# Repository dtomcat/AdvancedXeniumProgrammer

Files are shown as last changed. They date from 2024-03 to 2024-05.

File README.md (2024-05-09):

# OpenXenium JTAG and Flash Memory Chip programmer

**This is based on work done by [kooscode](https://github.com/kooscode/xenium-programmer) and [Ryzee119](https://github.com/ryzee119/openxenium) with modifications to program the bare ICs.  Most of the code here was done by kooscode (please visit the link above).

--------------

## * Read: ["Home Brew" on ORIGINAL XBOX](XBOX.md) - a detailed article on why and how *

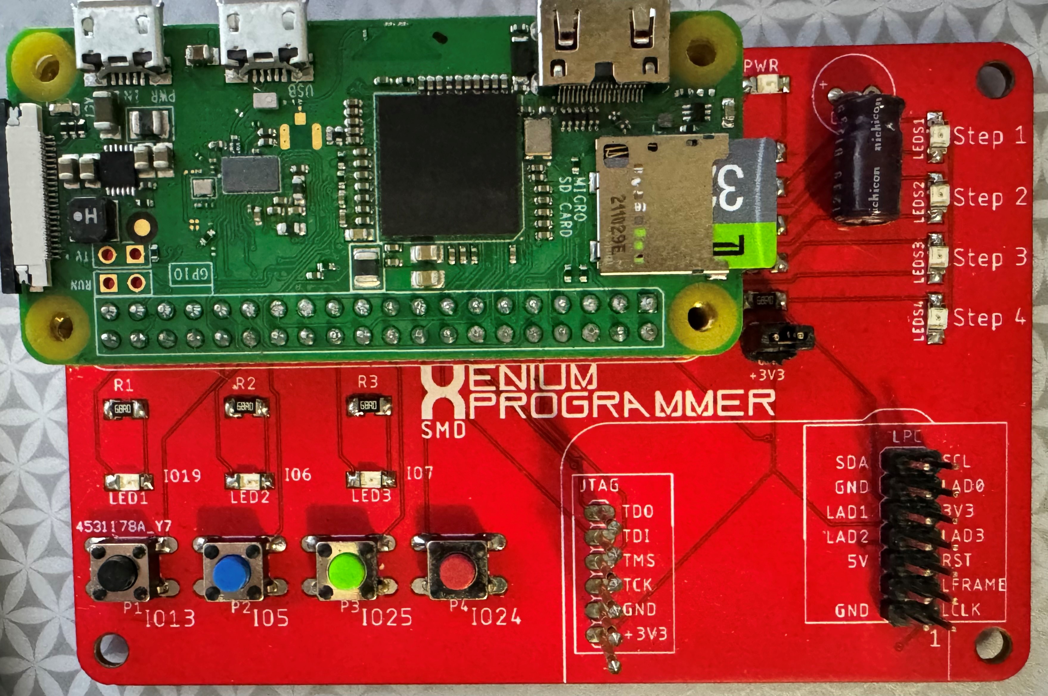
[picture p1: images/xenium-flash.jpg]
xenium-programmer


The tools in this repo will allow you to use a Raspberry PI to program the CPLD and Flash Memory chips of the OpenXenium via Jtag and a custom 4-bit bus NOR Flash programming protocol.
Original project mentioned above allowed the use of an Onion Omega2+... This has been removed for this project. 

### Raspberry PI:
- This has only been tested on PI Zero W and PI 3B+ models so far.

https://www.pishop.us/product/raspberry-pi-zero-w/

-------------
## INSTALLING THE XENIUM PROGRAMMER
**The scripts assumes user of "pi"...  if using a different user, you'll need to manually change "pi" to your username in the scripts**
- After the OS has been written to your SD card, insert SD card into PC.
    - Add the following to the last line in "config.txt":   `enable_uart=1`
        - This is required to allow the PWR LED to function properly.
- Save edit and eject SD Card.  Insert SD card into Pi and boot up.
- Connect to the PI via SSH or Serial terminal
- If git is not installed, you need to install it:
    - `sudo apt-get install git`
- Clone this repo by running: `git clone https://github.com/dtomcat/AdvancedXeniumProgrammer.git`
- Change to program directory: `cd AdvancedXeniumProgrammer`
- Fix permission on install file:  `chmod 755 install`
- Then run: `./install`
- Setup service to listen for button presses:
    - `sudo cp xenium.service /etc/systemd/system/xenium.service`
    - `sudo systemctl daemon-reload`
    - `sudo systemctl enable xenium`
    - `sudo service xenium start`

## UPDATING XENIUM PROGRAMMER

- Connect to the PI via SSH or Serial terminal 
- Pull the latest code with: `git pull`
- Then run: `./install` 

-------------
## STATUS LED MEANING (From top to bottom)

- First:  Programming CPLD with BIT BANG firmware
- Second: Programming Flash with specified OS
- Third:  Verifying flash was programmed successfully
- Forth:  Programing CPLD with OpenXenium firmware

-------------
## PROGRAMMING THE XENIUM CPLD AND/OR FLASH MEMORY (STANDALONE)

Note: You will need to provide your own PrometheOS bin file. (save it in the /xenium-bin folder as promOS.bin)

- After the PI has fully booted and the green led is on...
    - Press the FIRST button to program the OpenXenium with XeniumOS.
    - Hold the FIRST button to program the OpenXenium with PrometheOS.
    - Press the SECOND button to program the flash chip with XeniumOS. (**The CPLD must be programmed with the Bit Bang firmware or this will fail.)
    - Hold the SECOND button to program the flash chip with PrometheOS. (**The CPLD must be programmed with the Bit Bang firmware or this will fail.)
    - Press the THIRD button to program the CPLD with the OpenXenium Firmware.
    - Hold the THIRD button to program the CPLD with the BitBang Firmware.
    - Press the FOURTH button to clear any errors.
    - Hold the FOURTH button to shutdown the Raspberry Pi.

-------------
## PROGRAMMING THE XENIUM CPLD AND/OR FLASH MEMORY (SSH/SERIAL)
This is good to do if you keep getting an error trying to program the chips. (Red LED remains on)

Note: You will need to provide your own PrometheOS bin file. (save it in the /xenium-bin folder as promOS.bin)

- Connect to the PI via SSH or Serial terminal
- Change dir to AdvancedXeniumProgrammer
- You can program CPLD and FLASH in one single step with XeniumOS (XOS).
    - Run: `./xenium-programmer-smd`
- You can program CPLD and FLASH in one single step with PrometheOS (PromOS).
    - Run: `./PromOS-programmer-smd`
- You can program just the CPLD in one two ways.
    - To program the Bit Bang firmware: 
        - Run: `./BitBangOnly`
    - To program the OpenXenium firmware: 
        - Run: `./OX-Only_SMD`
- You can program just the Flash in oe of two ways. (The CPLD MUST have the Bit Bang Firmware loaded)
    - To program XOS:
          - Run: `./FlashOnly`
    - To program PromOS:
          - Run: `./FlashOnlyProm`

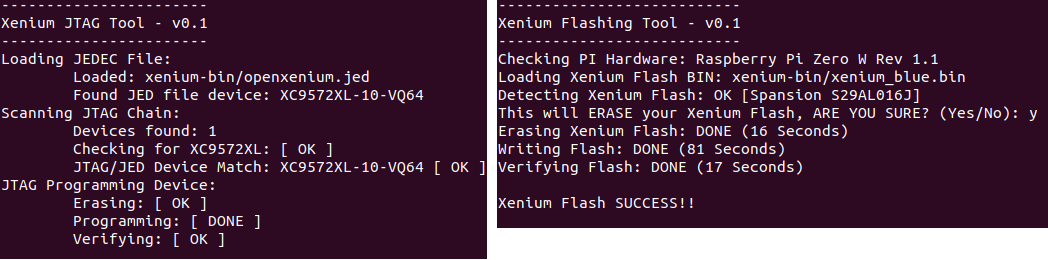
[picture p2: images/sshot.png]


-------------
### 3D PRINTED CASE

Just a quick and simple design I put together.  I'm sure this thing could be improved upon greatly.  Sharing for anyone wanting it.

NOTE:  for the "light pipes", I just used some clear PLA (2.90mm not standard 1.75) filament. 

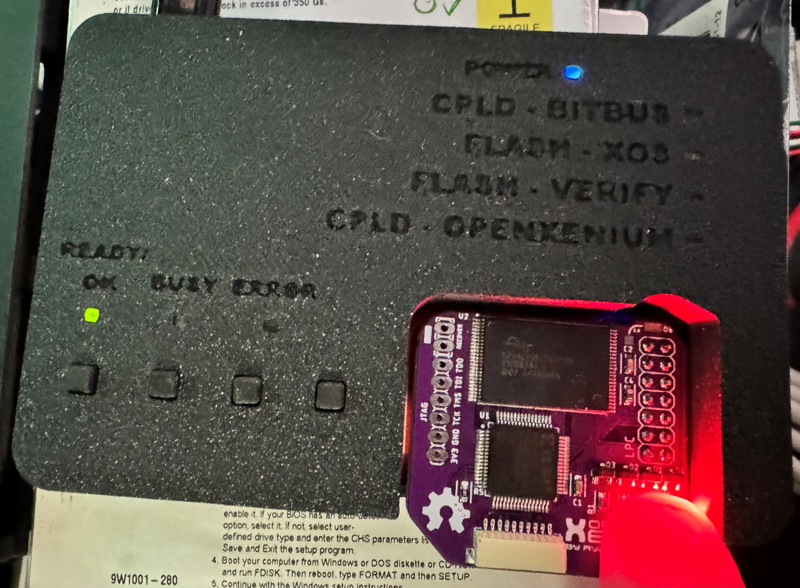
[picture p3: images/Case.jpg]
3D Case


--------------
### PC BOARD

Huge thanks to James Bolding for the Original Eagle PCB hardware design!
This PCB design is based on his original work.  

- You can use the FREE Eagle PCB to load this up or just use the gerber files to have the PCB made at OSH Park!

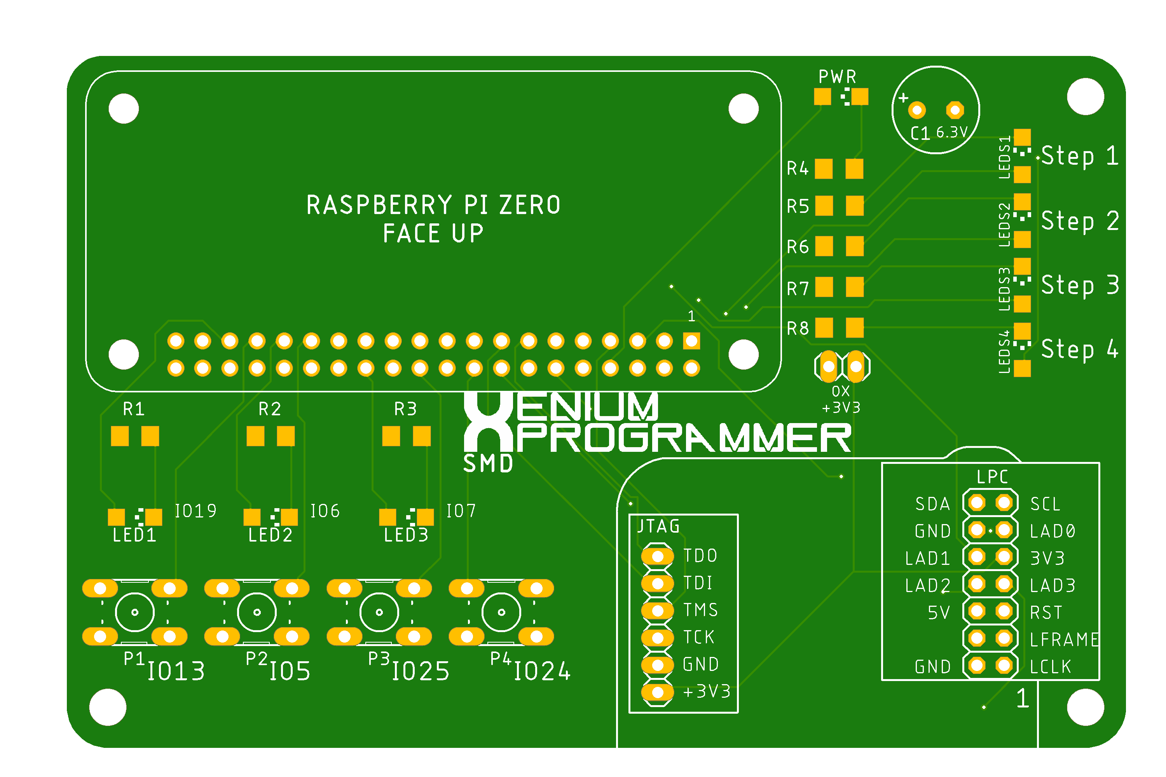
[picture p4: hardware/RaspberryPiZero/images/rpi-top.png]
RPI PCB


--------------

### PARTS NOT LISTED IN BOM
There are a couple parts not listed in BOM that could be helpful.
- Pin headers 2.54 spacing
    - 1 2x7 for LPC port
    - 1 1x2 for 3v3 (Optionally... but connect two points with solder)
        - Will need a 2-Pin Jumper/Bridge Cap if installing 1x2 pin header
- 6 Pogo pins (P75-E3 pogo pins seem to work the best)

-------------
## CREDITS

- Koos du Preez - Creator (kdupreez@hotmail.com - Comments, improvements, critique, etc. is welcome!)
- Dtomcat - SMD programmer PCB design and code split to allow status LEDs.
- James Bolding - Orignal hardware design and PCB!
- Ryzee119 -  OpenXenium Firmware and hardware and all round awesomeness!
- XC3SPROG - Not sure who to thank here, but the source code was pivotal in making this work!

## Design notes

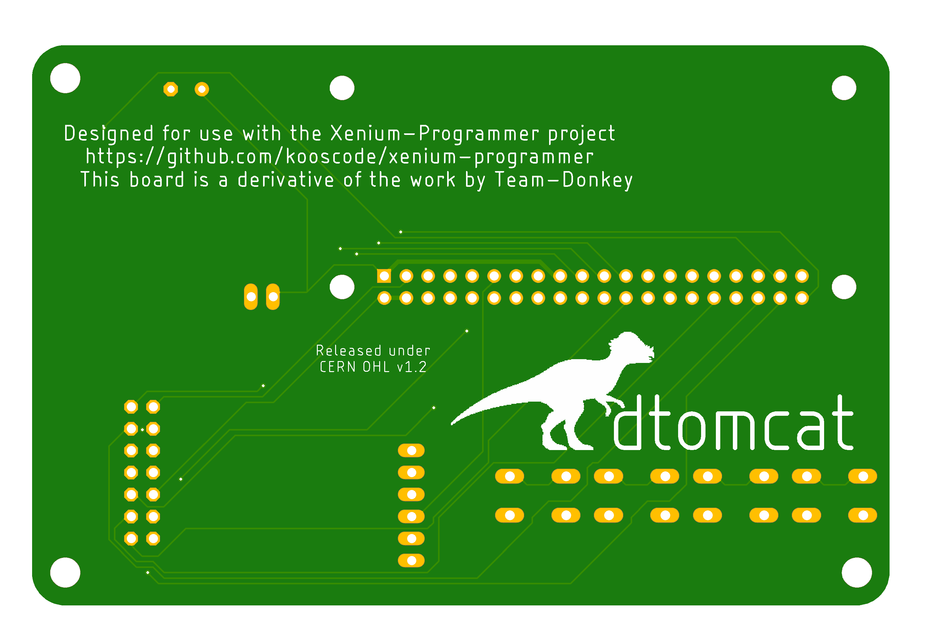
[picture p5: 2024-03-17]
hardware/RaspberryPiZero/images/rpi-bottom.png

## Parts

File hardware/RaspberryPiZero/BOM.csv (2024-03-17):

Reference | Qty | Description | Part Number | Manufacturer | Digikey
R1,R2,R3,R5,R6,R7,R8 | 7 | RES 68 OHM 1% 1/4W 1206 | RC1206FR-1068RL | YAGEO | 13-RC1206FR-1068RLCT-ND
R4 | 1 | RES 15 OHM 1% 1/4W 1206 | RC1206FR-1015RL | YAGEO | 13-RC1206FR-1015RLCT-ND
PWR | 1 | LED BLUE CLEAR 1206 SMD | LTST-C150TBKT | Lite-On Inc. | 160-1643-1-ND
LED1 | 1 | LED GREEN CLEAR 1206 SMD | LTST-C150KGKT | Lite-On Inc. | 160-1404-1-ND
LED2 | 1 | LED YELLOW CLEAR 1206 SMD | LTST-C150KSKT | Lite-On Inc. | 160-1406-1-ND
LED3 | 1 | LED RED CLEAR 1206 SMD | LTST-C150KRKT | Lite-On Inc. | 160-1405-1-ND
LEDS1,LEDS2,LEDS3,LEDS4 | 4 | LED ORANGE CLEAR 1206 SMD | LTST-C150KFKT | Lite-On Inc. | 160-1403-1-ND
C1 | 1 | CAP ALUM 150UF 20% 6.3V RADIAL | UPW0J151MED | Nichicon | 493-1698-ND
P1,P2,P3,P4 | 4 | SWITCH TACTILE SPST-NO 0.05A 24V | 1825910-6 | TE Connectivity ALCOSWITCH Switches | 450-1650-ND
RPI-CONN | 1 | CONN HDR 40POS 0.1 TIN PCB | PPTC202LFBN-RC | Sullins Connector Solutions | S6104-ND

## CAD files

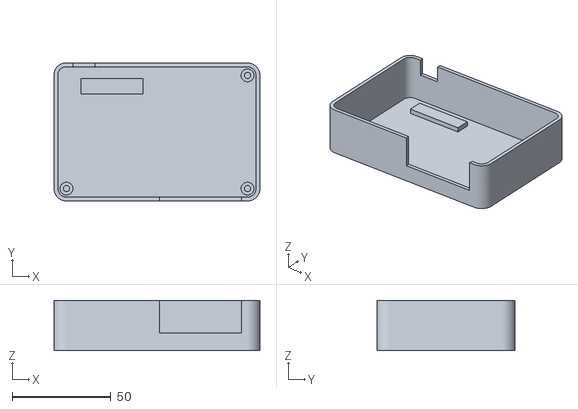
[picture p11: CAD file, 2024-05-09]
3D Case/ADV case Base.stl
104.1 x 69.8 x 25.5

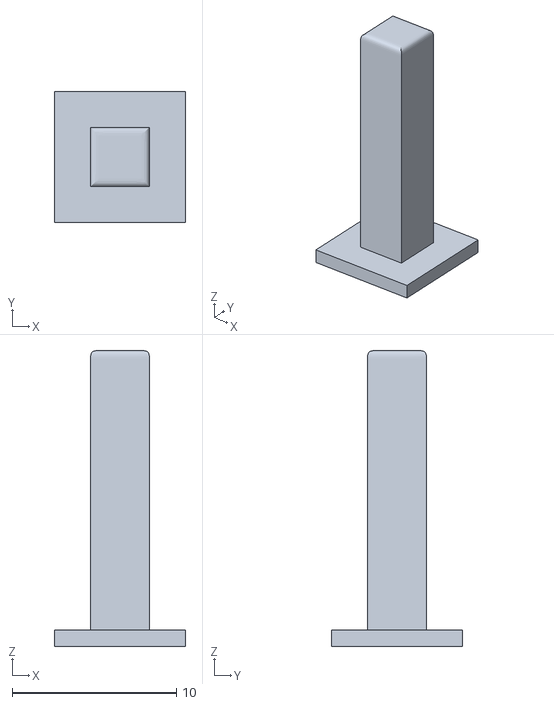
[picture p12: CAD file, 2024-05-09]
3D Case/ADV case Button.stl
7.99 x 7.99 x 18.0

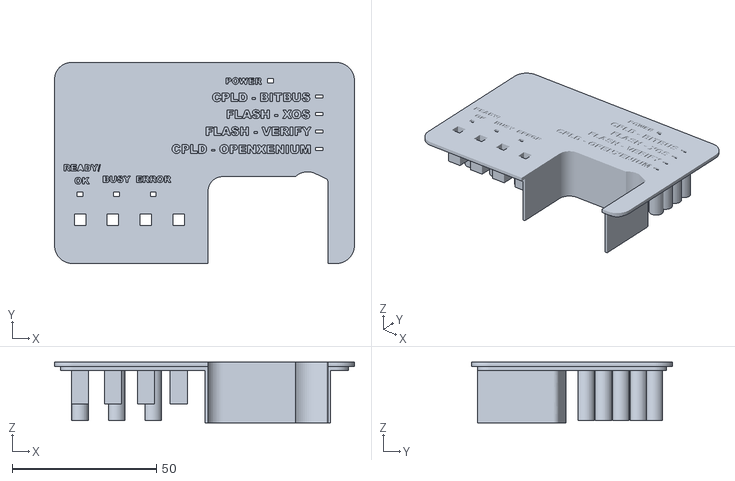
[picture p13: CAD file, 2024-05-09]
3D Case/ADV Case Lid.stl
104.1 x 69.8 x 21.1

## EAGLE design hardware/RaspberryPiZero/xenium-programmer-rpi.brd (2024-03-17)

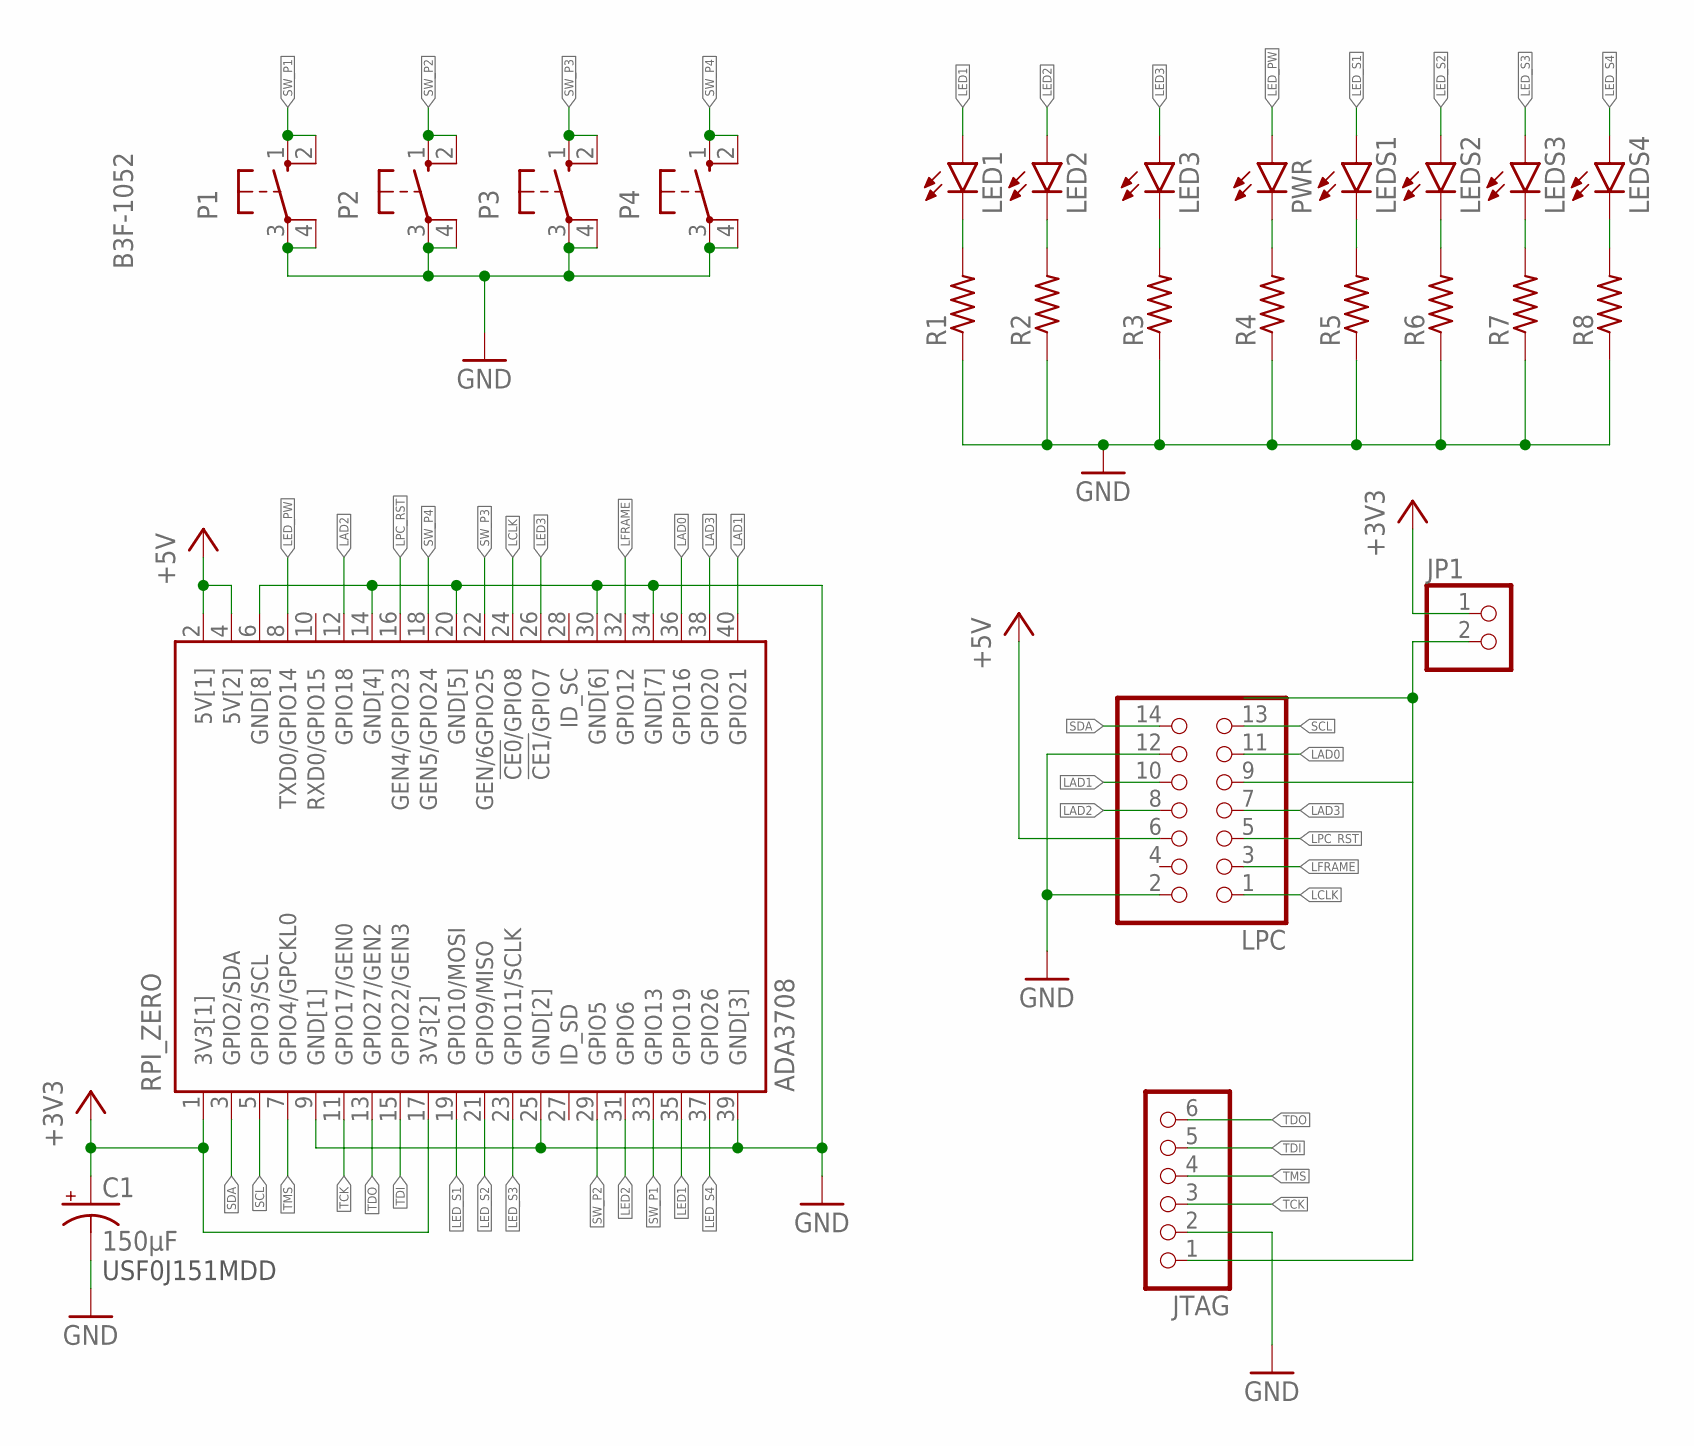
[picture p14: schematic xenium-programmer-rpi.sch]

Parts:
C1: 150µF; E3,5-8
JP1: PINHD-1X2; 1X02
JTAG: PINHD-1X6; 1X06
LED1, LED2, LED3: LEDCHIPLED_1206; CHIPLED_1206
LEDS1, LEDS2, LEDS3, LEDS4: LEDCHIPLED_1206; CHIPLED_1206
LPC: PINHD-2X7; 2X07
P1, P2, P3, P4: B3F-1052; B3F-10XX
PWR: LEDCHIPLED_1206; CHIPLED_1206
R1, R2, R3, R4, R5, R6, R7, R8: R-US_R1206; R1206
RPI_ZERO: ADA3708; ADA3708_RPI-ZERO

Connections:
+3V3: C1.+, JP1.1, RPI_ZERO.1 (3V3[1]), RPI_ZERO.17 (3V3[2])
+5V: LPC.6, RPI_ZERO.2 (5V[1]), RPI_ZERO.4 (5V[2])
GND: C1.-, JTAG.2, LPC.2, LPC.12, P1.3, P1.4 (P1), P2.3, P2.4 (P1), P3.3, P3.4 (P1), P4.3, P4.4 (P1), R1.1, R2.1, R3.1, R4.1, R5.1, R6.1, R7.1, R8.1, RPI_ZERO.6 (GND[8]), RPI_ZERO.9 (GND[1]), RPI_ZERO.14 (GND[4]), RPI_ZERO.20 (GND[5]), RPI_ZERO.25 (GND[2]), RPI_ZERO.30 (GND[6]), RPI_ZERO.34 (GND[7]), RPI_ZERO.39 (GND[3])
LAD0: LPC.11, RPI_ZERO.36 (GPIO16)
LAD1: LPC.10, RPI_ZERO.40 (GPIO21)
LAD2: LPC.8, RPI_ZERO.12 (GPIO18)
LAD3: LPC.7, RPI_ZERO.38 (GPIO20)
LCLK: LPC.1, RPI_ZERO.24 (!CE0!/GPIO8)
LED1: LED1.A, RPI_ZERO.35 (GPIO19)
LED2: LED2.A, RPI_ZERO.31 (GPIO6)
LED3: LED3.A, RPI_ZERO.26 (!CE1/!GPIO7)
LED_PW: PWR.A, RPI_ZERO.8 (TXD0/GPIO14)
LED_S1: LEDS1.A, RPI_ZERO.19 (GPIO10/MOSI)
LED_S2: LEDS2.A, RPI_ZERO.21 (GPIO9/MISO)
LED_S3: LEDS3.A, RPI_ZERO.23 (GPIO11/SCLK)
LED_S4: LEDS4.A, RPI_ZERO.37 (GPIO26)
LFRAME: LPC.3, RPI_ZERO.32 (GPIO12)
LPC_RST: LPC.5, RPI_ZERO.16 (GEN4/GPIO23)
unnamed: LED1.C, R1.2
unnamed: LED2.C, R2.2
unnamed: LED3.C, R3.2
unnamed: PWR.C, R4.2
unnamed: JP1.2, JTAG.1, LPC.9
unnamed: LEDS1.C, R5.2
unnamed: LEDS2.C, R6.2
unnamed: LEDS3.C, R7.2
unnamed: LEDS4.C, R8.2
SCL: LPC.13, RPI_ZERO.5 (GPIO3/SCL)
SDA: LPC.14, RPI_ZERO.3 (GPIO2/SDA)
SW_P1: P1.1 (S), P1.2 (S1), RPI_ZERO.33 (GPIO13)
SW_P2: P2.1 (S), P2.2 (S1), RPI_ZERO.29 (GPIO5)
SW_P3: P3.1 (S), P3.2 (S1), RPI_ZERO.22 (GEN/6GPIO25)
SW_P4: P4.1 (S), P4.2 (S1), RPI_ZERO.18 (GEN5/GPIO24)
TCK: JTAG.3, RPI_ZERO.11 (GPIO17/GEN0)
TDI: JTAG.5, RPI_ZERO.15 (GPIO22/GEN3)
TDO: JTAG.6, RPI_ZERO.13 (GPIO27/GEN2)
TMS: JTAG.4, RPI_ZERO.7 (GPIO4/GPCKL0)

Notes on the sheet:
USF0J151MDD

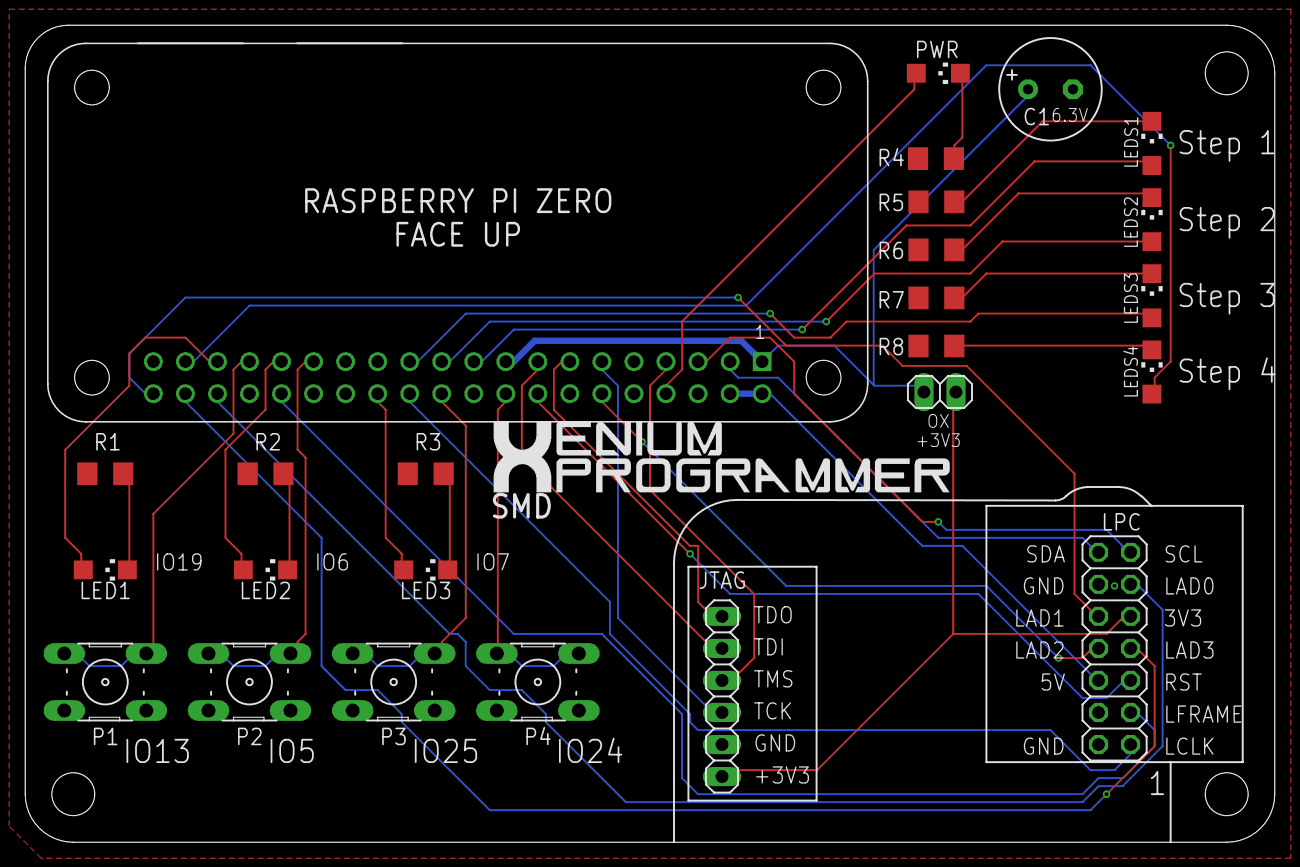
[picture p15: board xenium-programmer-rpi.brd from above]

Board: 2 copper layers, 99.1 x 64.8 mm, 25 parts (0 on the bottom side), 37 nets.

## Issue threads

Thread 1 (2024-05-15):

Accessing PrometheOS bin

falconmick, 2024-05-15:
Hey!

very new to Xbox modding scene, was wondering how people typically get a copy of PrometheOS‘a bin? From what I can see from quick googling everyone uses xbins pandora but using a random exe to download files kinda has all the hallmarks of sketchiness and I’m just confused why it isn’t just a web portal which makes me unsure if it’s the correct approach.

cheers

falconmick, 2024-05-16:
also not to open 2 issues, what is the point of the 3.3v 2 pin slot? I cannot see it plugged into anything so I am at a loss

dtomcat, 2024-05-16:
PrometheOS isn’t my work and that’s just how it’s distributed. I can say that people download it with how you explained above without issue… but I understand your concern…. The 3.3v connects pi’s 3.3v to the OX. I just carried it over from original design… you can just bridge it on PCB with solder instead of a pin header if you like

dtomcat, 2024-05-16:
I’ll close this since you answered the question :). Sorry I can’t help more   I was advised to host it on my GitHub.

falconmick, 2024-05-16:
Cheers :)

I've got a pcb in the mail and the components are also in the mail so I'm looking forward to the build!

Oh if you have the 3d cad model for the case still kicking around I would love to re-mix it to update the text to be additive to the top so I can use my printers filament swapping to make nice crisp letters :)

Closed 2024-05-16.

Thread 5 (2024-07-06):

Buttons/Wiring/Rasberry Pi Zero/ Not working / Responding

petrolhead77, 2024-07-06:
I dont get the buttons to co-work with the Pi Zero.
(Program throu commands works 100%)

Did update after install.

My OS Raspian Pie Lite

Best regards Conny

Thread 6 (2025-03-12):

lgpio.error: 'GPIO not allocated' on Pi Zero 2 W

braxtron, 2025-03-12:
All flashing programs result in the following

Traceback (most recent call last):
  File "/home/pi/AdvancedXeniumProgrammer/./FlashOnlyProm", line 120, in <module>
    GPIO.setup(led1, GPIO.OUT)
  File "/usr/lib/python3/dist-packages/RPi/GPIO/__init__.py", line 704, in setup
    initial = _check(lgpio.gpio_read(_chip, gpio))
                     ^^^^^^^^^^^^^^^^^^^^^^^^^^^^
  File "/usr/lib/python3/dist-packages/lgpio.py", line 903, in gpio_read
    return _u2i(_lgpio._gpio_read(handle&0xffff, gpio))
           ^^^^^^^^^^^^^^^^^^^^^^^^^^^^^^^^^^^^^^^^^^^^
  File "/usr/lib/python3/dist-packages/lgpio.py", line 458, in _u2i
    raise error(error_text(v))
lgpio.error: 'GPIO not allocated'

braxtron, 2025-03-12:
i quadruple checked all the permissions around gpio and made sure my user was part of that group and the issue persists.

braxtron, 2025-03-13:
Got rid of all the GPIO stuff and was able to program and flash some OXes! I don't need the blinking lights anyway.

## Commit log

2024-03-17 Initial
    Initial Upload
    [BOM.csv, xenium-programmer-rpi.brd, xenium-programmer-rpi.sch]
2024-05-09 Add 3d printed case and explain status LEDs
    [ADV Case Lid.stl, ADV case Base.stl, ADV case Button.stl]
2024-05-09 Put 3D Case into folder
    [ADV Case Lid.stl, ADV case Base.stl, ADV case Button.stl]
2026-01-09 Update install
    Implemented a fix for wiringpi since drogon.net took it offline.

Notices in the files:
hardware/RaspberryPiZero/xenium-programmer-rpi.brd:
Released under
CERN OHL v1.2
